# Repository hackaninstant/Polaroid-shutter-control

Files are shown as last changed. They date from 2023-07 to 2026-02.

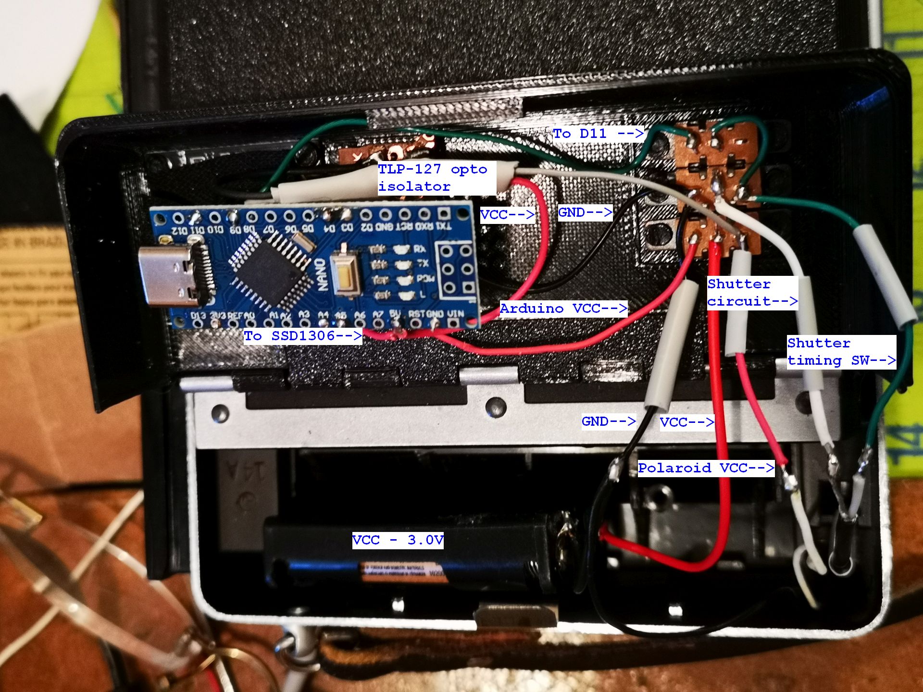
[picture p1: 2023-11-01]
Polaroid manual shutter wiring.jpg

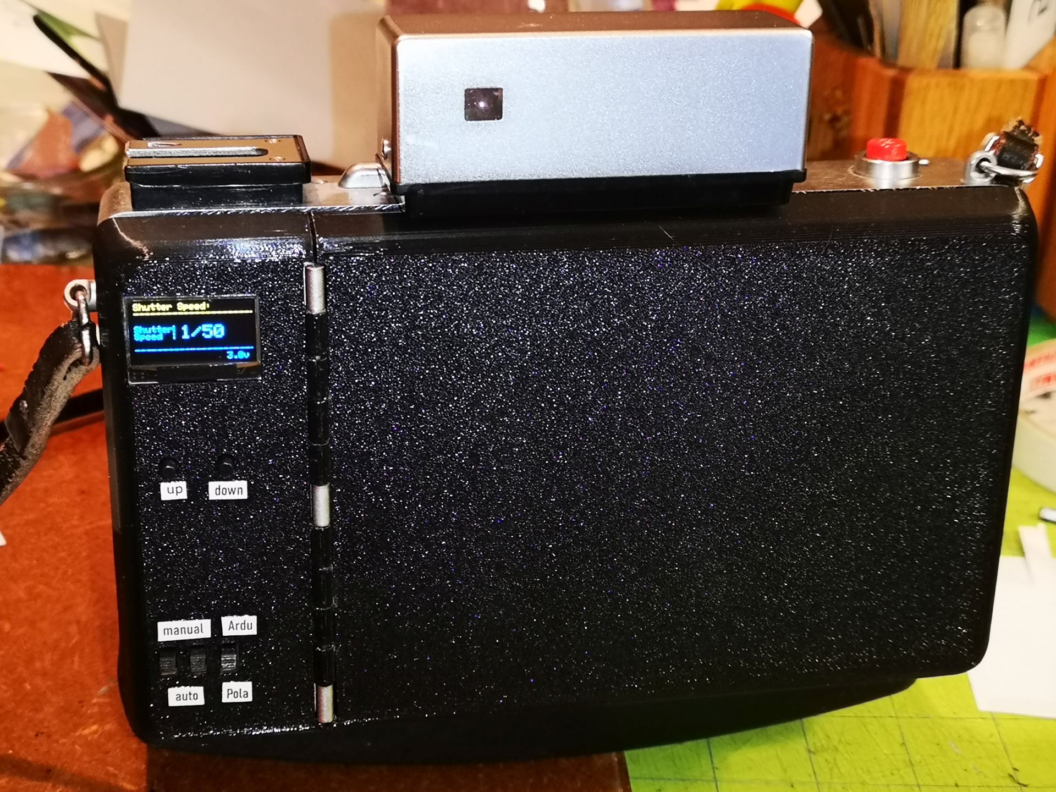
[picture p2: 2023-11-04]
Polaroid manual shutter1.jpg

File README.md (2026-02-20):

# Polaroid-shutter-control
An arduino project which gives automatic Polaroid pack cameras manual shutter speeds

This project is specifically made for automatic Polaroid pack film cameras with a bellows and will work with models with extra apertures/ASA speeds as well as the simple version with just two apertures/ASA settings. It basically gives these fully automatic exposure cameras manual shutter speed capability. Step by step instructions are posted at http://polaroids.theskeltons.org/manuale.htm.

This project uses the SSD1306ASCII.h library for display since graphics aren't needed and the libraries are smaller. 

# Features:

- small footprint: will work with Nano Mega 168 boards
- push button switch and/or rotary encoder operation
- shutters speeds from 2 seconds to 1/1500 in 1/3 stop increments (can be modified in the code)
- operates on same battery power as the Polaroid camera
- switchable between manual and auto exposure mode

# Requirements:

- Polaroid pack film camera (with a bellows), ie. models 100 - 455 
- Arduino nano (will work with the mega 168, 16K version)
- SSD1306 oLED display
- rotary encoder (optional)
- TLP127 opto-isolator and 330 Ohm resistor
- 2 momentary button switches

# Arduino Nano Configuration:

- D3: button switch (DOWN)
- D4: button switch (UP)
- D7: rotary encoder CLK (optional)
- D8: rotary encoder DT (optional)
- D9: 330 Ohm resistor, then to TLP 127 opto isolator
- D11: to shutter timer switch on Polaroid
- A4: SDA on I2C SSD1306
- A5: SCL on I2C SSD1306
- 3.3V: VCC on I2C SSD1306
- 5.0v: + on battery source from Polaroid (4.5 or 3.0 volts)
- GND: GND on SSD1306, pin 3 on TLP 127, button switches, GND side of shutter timing switch on Polaroid

# SSD1306 oLED display:

- SDA: A4 on Nano
- SCL: A5 on Nano
- GND: GND on Nano
- VCC: 3.3v on Nano

# TLP127 Opto Isolator:

 - Pin 1 (Anode): 330 Ohm resistor, then to D9
 - Pin 3 (Cathode): GND on Nano
 - Pin 4 (Emitter): VCC on camera
 - Pin 6 (Collector): VCC on battery

   pinouts:

   `6    4`  
   `------`  
   `|    |`  
   `|O   |`  
   `------`  
   ` 1   3`  

# Rotary Encoder (optional):

- GND: GND on Nano
- VCC: 5v on Nano
- CLK: Pin D7 on Nano
- DT: Pin D8 on Nano
- SW: not used

Two momentary switches are sufficient for choosing shutter speeds, and the button delay can be modified before uploading. A rotary encoder is coded in, but they are somewhat large and don't fit easily into the battery compartment of the camera. 

To operate, choose the desired shutter speed, then cock the shutter. Once the shutter is cocked, you cannot change the shutter speed as the program is dedicated to waiting for the first shutter blade to open, and timing is critical for high shutter speeds. Keep the shutter pressed down during the duration of the exposure, at which time you can choose a different shutter speed. Should you need to change shutter speeds after cocking the shutter, keep the arduino power on, and switch the left hand switch down. The arduino will be disconnected from the shutter timing switch, allowing you to change the shutter speed. Ensure that the left switch is up before releasing the shutter or the shutter will fire with no power, with the closing shutter blade immediately following the opening blade. 

# Integration with a Polaroid Pack film camera:

Reference the file "Polaroid Modification.jpg". This project needs access to the shutter timing switch on the Polaroid shutter. Disassemble the shutter body, remove the circuit/shutter from the lens body and flip upside down, with the camera facing you. On the upper right, to the left of the cocking lever, there are 2 solder contacts connected to the shutter timing switch. You will need to desolder the upper terminal (remember, the shutter is upside down so it shows as the lower terminal in the photo) which connects the timing switch to the shutter circuit. The lower terminal connects to ground and stays intact. After desoldering, If you want to retain the option to use auto exposure, connect a wire to the desoldered contact on the ribbon cable (careful not to melt it). Connect a wire to the timing switch underneath the ribbon. You should insulate that contact from the ribbon cable to prevent contact since you want to isolate the shutter circuit from the timing switch. Label the wires connected to the switch ("Timing switch), and to the ribbon cable (Shutter circuit) and route them to the battery compartment of the camera. If you do not want to retain auto exposure capability, you need to solder a wire from S2 on the circuit ribbon to GND (the solder terminal next to it). 

To test the Polaroid shutter circuit wiring, short out the two wires you just connected and operate the shutter. It should work in automatic exposure mode. Then, connect the shutter circuit wire to ground and try the shutter. If the shutter stays open (bulb), then it should be wired correctly. It's ready to connect to the arduino circuit. 

If you want to be able to switch between auto and manual shutter control, you will need a DPDT and an SPDT switch (or 3 SPDT switches) and wire the arduino/camera using the Polariod integration schematic using the DPDT switch (or 2 SPDT switches) to configure the camera between auto and manual shutter control. By using a separate SPDT switch to switch power between the arduino and camera, you can shoot with "bulb" by switching this switch to Polaroid (auto), and keeping the DPDT switch on manual. 

A 3D printable file is included to help install the screen and switches onto the battery door of a Polaroid pack film camera. The battery compartment wiring file shows a photo of how this is typically wired to the Polaroid camera. 

# Principles of operation:

While the arduino is controlling the Polaroid shutter, the Polaroid shutter circuit is connected to ground, which discharges the internal capacitors and keeps the shutter open. This effectively puts the camera into "bulb" mode. The arduino de-energizes the Polaroid shutter circuit and is waiting for the shutter to be cocked (sensed by the shutter timing switch closing) at which point, the arduino energizes the Polaroid camera circuit by turning on the opto-isolator and effectively connecting battery power to the Polaroid. Having said this, no power is being used by the Polaroid circuit until the shutter is pressed. When the shutter is pressed, a switch energizes the solenoid which holds back the second shutter curtain and opens the first shutter curtain, also opening the shutter timing switch. Once the arduino detects the shutter open (timing switch open), it times the exposure, then cuts off power to the camera, de-energizing the solendoid and closing the shutter. 

# The Basics: How to get setup with the Arduino and program it:

If you are just getting started with Arduino, here are some instructions to get going. 

1. Download and install Arduino IDE from here: https://www.arduino.cc/en/software
2. Under tools, manage libraries, search for and install SSD1306ASCII by Bill Greiman (this should be the only external library needed).
3. In Arduino IDE, go to File, New Sketch, and erase everything in the new window.
4. Go to the code from this page (polaroidshutter.ino) and put your cursor inside the code window and press ctrl-A then ctrl-C to copy the code
5. Back to Arduino IDE, put your cursor inside the new code window and press ctrl-V to paste the code
6. Connect an Arduino nano to a USB cable on the computer
7. In the toolbar below the menu, a white box will indicate the arduino devices available. Click on the down arrow to see what's there. Select the COM port that's listed there
8. In the window that opens, choose the Nano. The device should now be selected.
9. Go to tools, processor, and select the processor that your nano is using: ATmega168 = 16K, ATmega328P = genuine arduino nano, ATmega328P (old bootloader) = generic (Chinese) nano.
10. Go to Sketch, Upload (or press <ctrl>U) to compile and upload the code to the nano

Once the code is uploaded and the Nano is connected to a display and switches, when you apply power it should start up and display the current shutter speed and be ready to control the shutter.

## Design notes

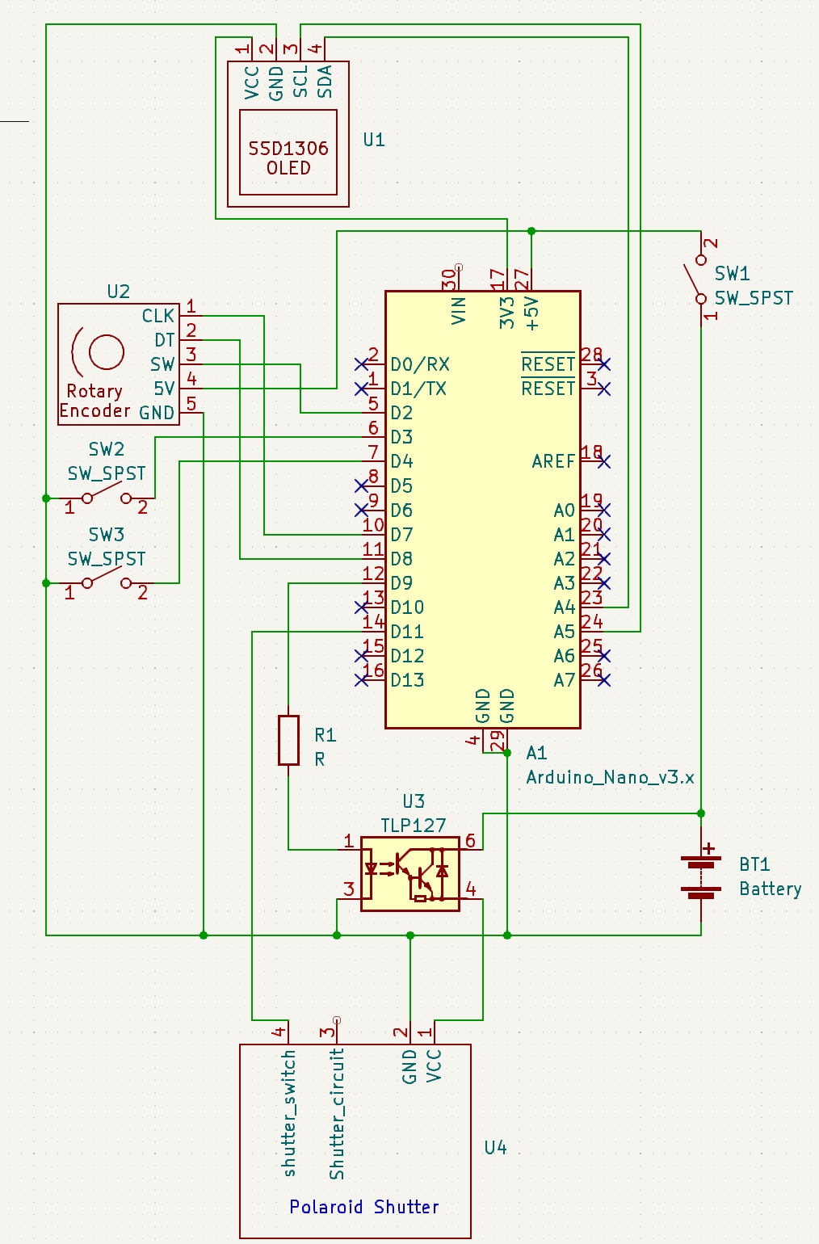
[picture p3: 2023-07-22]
PolaroidShutter Schematic.jpg

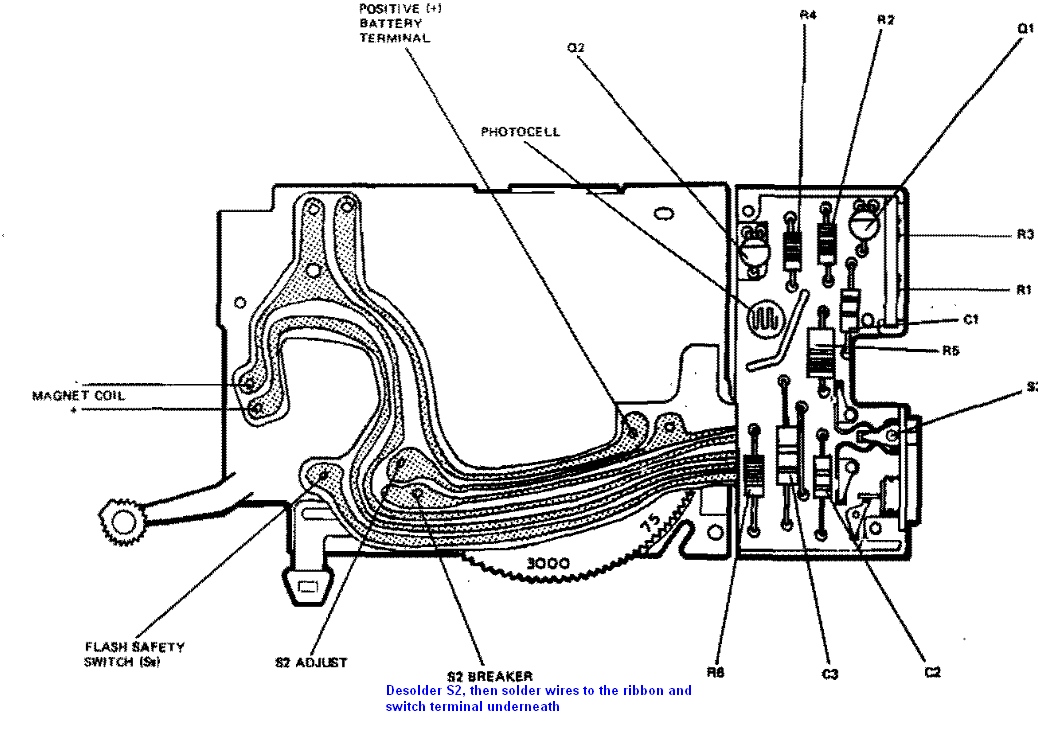
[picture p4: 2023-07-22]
Polaroid modification.jpg

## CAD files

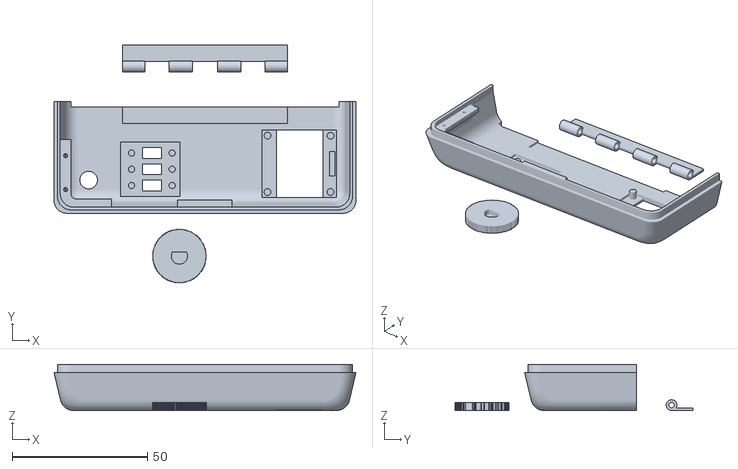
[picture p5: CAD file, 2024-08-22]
Polaroid battery compartment with dial v2.stl
111.6 x 88.0 x 17.0

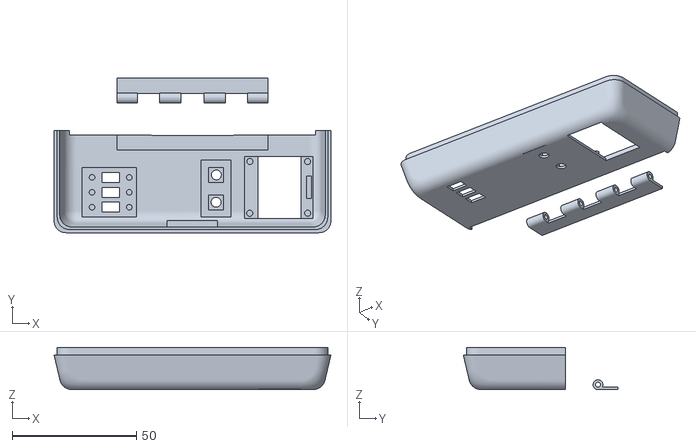
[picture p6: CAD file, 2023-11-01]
Polaroid battery compartment arduino.stl
111.6 x 62.3 x 17.0

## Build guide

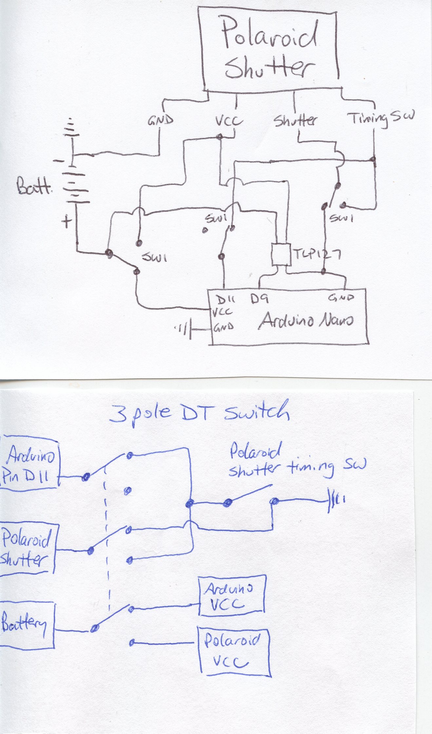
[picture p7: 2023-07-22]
Auto-Manual integration.jpg

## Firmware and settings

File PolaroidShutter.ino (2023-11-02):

#include <Wire.h>
#include "SSD1306Ascii.h"
#include "SSD1306AsciiWire.h"
#include <EEPROM.h>
#define I2C_ADDRESS 0x3C

// Define proper RST_PIN if required.
#define RST_PIN -1

SSD1306AsciiWire oled;

// Output pins:
#define powerPin                9                        // for opto-isolator, camera power switch

// Input pins:
#define shutterPin              11                      // shutter switch on Polaroid
#define PlusButtonPin           3                       // Plus button pin
#define MinusButtonPin          4                       // Minus button pin
#define rotButtonPin            6                       // rotary encoder switch
#define rotCLKPin               7                       // rotary encoder clock
#define rotDTPin                8                       // rotary encoder DT pin

boolean PlusButtonState;                // "+" button state
boolean MinusButtonState;               // "-" button state
boolean MenuButtonState;                // menu button state
boolean shutter;                        // shutter state
boolean cocked;                         // shutter cocked state
boolean mainmenu = true;                // main menu displayed
boolean adjustmenu = false;             // adjust menu displayed

// EEPROM for memory recording
#define ShutterSpeedAddr        1         // shutter speed
#define ButtonDelayAddr         2        // button repeat delay
#define TimerValuesAddr         3         // for timer values array

// default values if running for the first time

#define defaultButtonDelay      150       // button repeat delay
#define defaultShutterSpeedIndex 10       // default shutter speed
#define MaxShutterIndex         35        // matches number of items in spvalues to loop -1

// load values from EEPROM
uint8_t ShutterSpeedIndex =   EEPROM.read(ShutterSpeedAddr);
uint8_t buttondelay =         EEPROM.read(ButtonDelayAddr);
// unit8_t ShutterCocked =       EEPROM.read(ShutterCockedAddr);

float voltage = 0;                   // for storing voltage of battery

int rotcounter = 0;                  // counter for rotary enocoder
int currentStateCLK;                 // for rotary encoder
int lastStateCLK;                     // for rotary encoder
unsigned long lastButtonPress = 0;    // for rotary encoder
int btnState;                         // for rotary encoder
boolean rotaryencoder = false;        // for rotary encoder

// Shutter speed values in seconds. If you add/delete, modify MaxShutterIndex
// spvalues is the displayed shutter speed. timervalues is the actual amount of time that will be counted down
float spvalues[] =    {.00066667, .000833, .0010,  .00125, .0015625, .002, .0025, .003125,  .004, .0050, .00625, .008, .01, .0125, .0167, .02, .025, .033, .04, .05, .067, .08, .1, .125, .150, .200, .250, .300, .400, .500, .600, .800, 1.000, 1.250, 1.500, 2.000};
float timervalues[] = {.00045, .00065, .00085, .0011, .001420, .00182, .00230, .00290, .00375, .00475, .00623, .008, .01, .0125, .0167, .02, .025, .033, .04, .05, .067, .08, .1, .125, .150, .200, .250, .300, .400, .500, .600, .800, 1.000, 1.250, 1.500, 2.000};

// Store settings
void SaveSettings() {
  EEPROM.write(ShutterSpeedAddr, ShutterSpeedIndex);
}

// read button state
void readButtons() {
  PlusButtonState = digitalRead(PlusButtonPin);
  MinusButtonState = digitalRead(MinusButtonPin);
}

void readShutterState(){
  shutter = digitalRead(shutterPin);
}

// figure out what to do with button presses
void menu() {
  
// on main screen and a plus or minus button is pressed:

    if(PlusButtonState == 0) {
     if(ShutterSpeedIndex >= MaxShutterIndex) {
       ShutterSpeedIndex = 0;
      } else {
       ShutterSpeedIndex++;               // Increase shutter speed time
     }
    refreshShutter();                            // redisplay shutter speed
    SaveSettings();
   }
    if(MinusButtonState == 0) {
     if(ShutterSpeedIndex == 0) {
      ShutterSpeedIndex = MaxShutterIndex;
    } else {
     ShutterSpeedIndex--;                 // decrease shutter speed time
    }
    refreshShutter();                     // display shutter speed
    SaveSettings();
   }  
}


void printdivider(int row) {                // prints a divider
  oled.set1X();
  oled.setCursor(0, row);
  int count = 1;
  while (count < 23) {                      // 22 characters wide
    oled.print(F("-"));                     // choose your divider character...
   count++;
  }
}

// Display main screen
void refresh() {

  // Start main display
  oled.clear();
  oled.set1X();
  oled.setCursor(0, 0);
  oled.print(F("Shutter Speed:"));
  oled.setCursor(100,7);
  oled.print(voltage, 1);
  oled.print(F("v"));
  printdivider(1);
  printdivider(6);
  oled.set1X();
  oled.setCursor(40, 3);
  oled.print(F("|"));
  oled.setCursor(40, 4);
  oled.print(F("|"));
  oled.setCursor(0, 3);
  oled.print(F("Shutter"));
  oled.setCursor(0, 4);
  oled.print(F("Speed"));
  refreshShutter(); 

  delay(buttondelay);
}

void refreshShutter(){                        // display just shutter speed 
  float T = spvalues[ShutterSpeedIndex];      // get shutter speed from array
  uint8_t Tdisplay = 0;                       // Flag for shutter speed display style (fractional, seconds, minutes)
  double  Tfr = 0;                            // value for shutter speed fraction
  float   Tmin = 0;                           // shutter speed in minutes, if over 60 seconds
  if (T >= 60 && T <= 600) {
    Tdisplay = 0;                             // Exposure is in minutes
    Tmin = T / 60;

  } else if (T < 60 && T >= 0.6) {            // speed in seconds
    Tdisplay = 2;                             // Exposure in in seconds

  } else if (T < 0.6 && T >= .0001) {            // speed in fractions
    Tdisplay = 1;                             // Display is in fractional form
    Tfr = round(1 / T);
  }

  oled.set2X();
  oled.setCursor(50, 3);
  oled.print(F("       "));           // clear old shutter speed
  oled.setCursor(50, 3);              // reset cursor 
  if (Tdisplay == 0) {                // display shutter speed
    oled.print(Tmin, 1);              // in minutes
    oled.print(F("m"));
  } 
  if (Tdisplay == 1) {                // or in fractions
   if (T > 0) {
     oled.print(F("1/"));
     oled.print(Tfr, 0);
   }
  }
  if (Tdisplay == 2) {                // or in seconds
    oled.print(T, 1);
    oled.print(F("s"));
  }
  if(!rotaryencoder){         // if a button is being used, delay
  delay(buttondelay);
  }
  rotaryencoder = false;      // clear rotary encoder use flag
}

void setup() {
pinMode(PlusButtonPin, INPUT_PULLUP);         // setup buttons to pins
pinMode(MinusButtonPin, INPUT_PULLUP);
pinMode(shutterPin, INPUT_PULLUP);            // shutter switch on Polaroid
pinMode(powerPin, OUTPUT);                    // to transistor that switches on/off Polaroid
pinMode(rotCLKPin, INPUT);                    // setup rotary encoder
pinMode(rotDTPin, INPUT);
pinMode(rotButtonPin, INPUT_PULLUP);          // setup rotary encoder switch

lastStateCLK = digitalRead(rotCLKPin);        // read last state of CLK on rotary encoder

Wire.begin();
oled.begin(&Adafruit128x64, I2C_ADDRESS);     // setup oled address
oled.setFont(Adafruit5x7);                    // setup oled font

// load defaults if first time running
if (ShutterSpeedIndex > MaxShutterIndex) {
  ShutterSpeedIndex = defaultShutterSpeedIndex;
}
if (buttondelay > 250) {
  buttondelay = defaultButtonDelay;
  EEPROM.write(ButtonDelayAddr, buttondelay);
}

// get voltage
const long InternalReferenceVoltage = 1056L;  // Adjust this value to your boards specific internal BG voltage x1000
ADMUX = (0 << REFS1) | (1 << REFS0) | (0 << ADLAR) | (1 << MUX3) | (1 << MUX2) | (1 << MUX1) | (0 << MUX0);
delay(100);  // Let mux settle a little to get a more stable A/D conversion
ADCSRA |= _BV( ADSC );
while ( ( (ADCSRA & (1 << ADSC)) != 0 ) );
voltage = (((InternalReferenceVoltage * 1024L) / ADC) + 5L) / 10L; // calculates for straight line value
voltage = voltage/100;

digitalWrite(powerPin, LOW);                     // de-energize Polaroid camera

refresh();                                        // display main screen

}

void loop() {

// first thing's first -- check to see whether the shutter is cocked (shutterstate will trip high (on))
readShutterState();
if(!shutter){                                       // if the shutter is cocked (sensed by shutterstate tripping high (on))
 float shutterdelay = timervalues[ShutterSpeedIndex];  // get shutter speed
 shutterdelay = shutterdelay * 1000;                // convert to milliseconds
 digitalWrite(powerPin, HIGH);                      // engergize Polaroid (Polaroid itself will not turn on until shutter is pressed)
 cocked = true;                                     // indicate shutter as cocked
 oled.set1X();
 oled.setCursor(0,7);
 oled.print(F("cocked"));                            // indicate that shutter is cocked
 delay(300);                                        // give the shutterstate switch time to settle low
 int delayspeed = 1;
 if(shutterdelay < 8){
   delayspeed = 2;
 }
 switch(delayspeed){                                // branch depending on how to count delay
 case(1):                                           // shutter higher than 1/125
  while(!shutter){                                   // while the shutter is cocked but not fired
    readShutterState();                              // wait here until shutter is fired
 }    
 delay(shutterdelay);                               // wait until shutter speed time is up
 digitalWrite(powerPin, LOW);                       // de-energize the Polaroid to close shutter
 break;
 case(2):                                           // shutter below 1/125 count in microseconds
 shutterdelay = shutterdelay * 1000;                // convert to microseconds
  while(!shutter){                                   // while the shutter is cocked but not fired
    readShutterState();                              // wait here until shutter is fired
 }    
 delayMicroseconds(shutterdelay);
 digitalWrite(powerPin, LOW);
 break;
}
 refresh();
}

readButtons();                                // get button state

currentStateCLK = digitalRead(rotCLKPin);     // read current state of rotary encoder
if(lastStateCLK == LOW && currentStateCLK == HIGH){
  rotaryencoder = true;
  if(digitalRead(rotDTPin) == HIGH ){
    MinusButtonState = 0;                     // translate it to button state
  } else {
    PlusButtonState = 0;
  }
}
lastStateCLK = currentStateCLK;               // wait until next event from encoder

/*
btnState = digitalRead(rotButtonPin);             // read rotary encoder button
if (btnState == LOW){
  if (millis() - lastButtonPress > 50){
    MenuButtonState = 0;                      // translate encoder switcht to menu push
  }
  lastButtonPress = millis();
}
*/

menu();                                 // do stuff with button press

}

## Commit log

2023-07-20 Schematic diagram
2023-07-22 Arduino schematic
2023-07-22 Modification to Polaroid camera
2023-07-22 Schematic to integrate Polaroid with Arduino
    These schematics detail how to integrate the arduino with the Polaroid shutter allowing you to switch between auto and manual shutter control
2023-07-22 Prototype installed in camera
2023-07-22 Arduino/Polaroid integration
    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
2023-07-27 3D file for battery compartment
    [Battery compartment.stl]
2023-07-28 Battery compartment 3D printable file
    [Polaroid battery compartment.stl]
2023-07-28 Circuit installed into a Polaroid camera
2023-07-28 Shutter wiring photo inside battery compartment
2023-10-26 Battery compartment developed with Fusion 360
    [Polaroid battery compartment.stl]
2023-11-01 Updated 3d printable file for battery compartment
    [Polaroid battery compartment arduino.stl]
2023-11-01 Inside the battery compartment with labels
2023-11-04 Manual shutter battery compartment
2023-11-04 Pic of updated battery compartment
2024-08-22 Battery compartment for rotary encoder
    [Polaroid battery compartment with dial v2.stl]
